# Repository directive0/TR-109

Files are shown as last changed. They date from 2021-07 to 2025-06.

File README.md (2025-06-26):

#
This repository hosts a set of design documents for the TR-109 Mark I Picorder. A Picorder is a Raspberry Pi based handheld device that records and displays sensor data for immediate analysis. The TR-109 is designed to use a Raspberry Pi Zero W, a set of custom designed PCBs, and a 3D printed enclosure to achieve this goal. This project, along with [PicorderOS](https://squaredwave.com/wiki/index.php?title=PicorderOS) attempts to be a single self contained solution for anyone wishing to produce their own Picorder.

## What is included:

- The enclosure_design folder contains the .blend file used to produce the STLs for the case, diffusers and spacers. It also contains the main STLs ready to be printed, and an svg file to produce your own stickers.

- The pcb_design folder contains KiCad 5.1.10 files of both the main board, sensor board and indicator board pcbs. These files can be used to produce and test PCBs. There is some PCBWay files that may be useful with their Assembly service, but this is not finalized and may not work properly.

## What is not yet included:

- There are no assembly instructions. I hope to produce some in the future.

While it is not required, if you make a picorder using this repository I would appreciate you sharing photos or videos your build with me at chris@squaredwave.com.

For a more regularly updated description of this project please visit the [wiki](https://squaredwave.com/wiki/index.php?title=Picorder_2)

Originally designed by Chris Barrett in 2021. I consider this project to be "Open Hardware", and as such is free to use, modify distribute or sell. It comes with no promise of support or warranty.

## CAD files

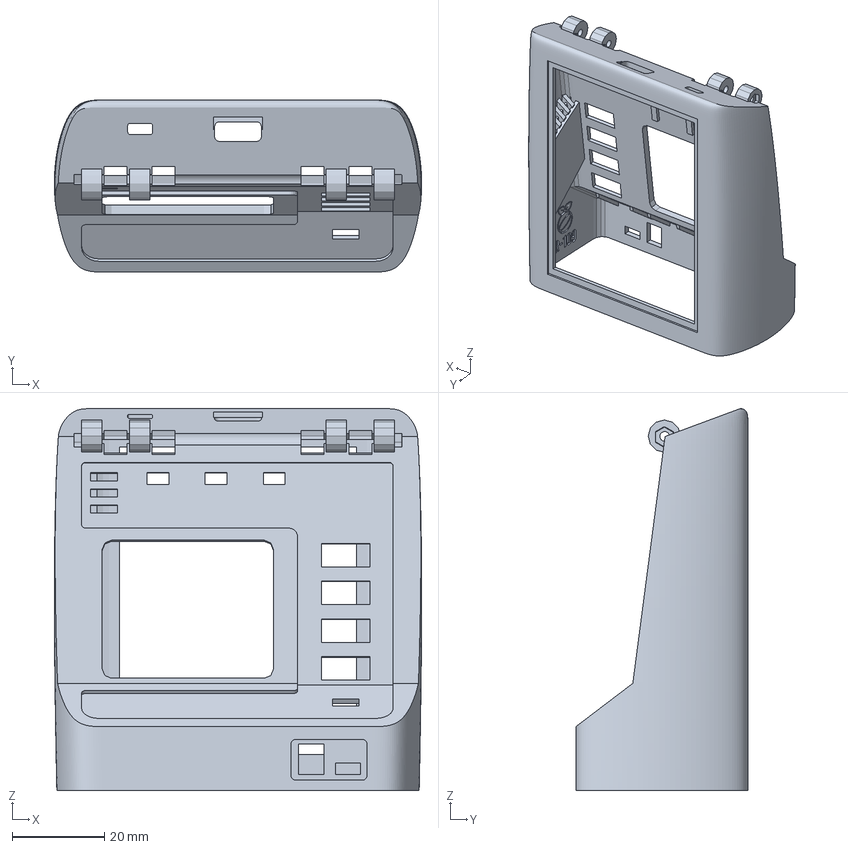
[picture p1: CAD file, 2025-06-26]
enclosure_design/Slicer Setup/TR109 - Main Body.3mf
79.5 x 37.3 x 82.7 mm

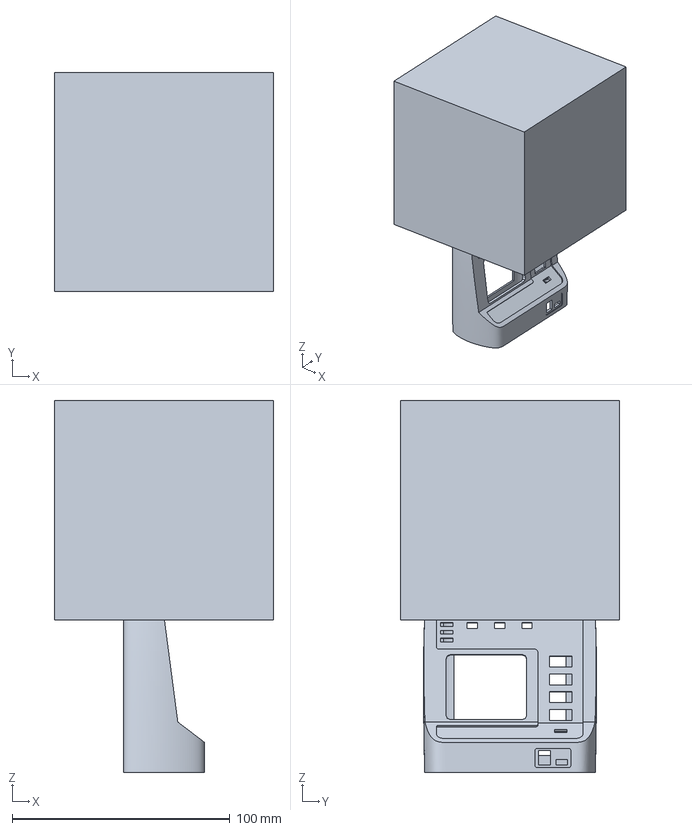
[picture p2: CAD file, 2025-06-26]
enclosure_design/Cura/TR109 - Main Body.3mf
100.8 x 100.8 x 170.9 mm

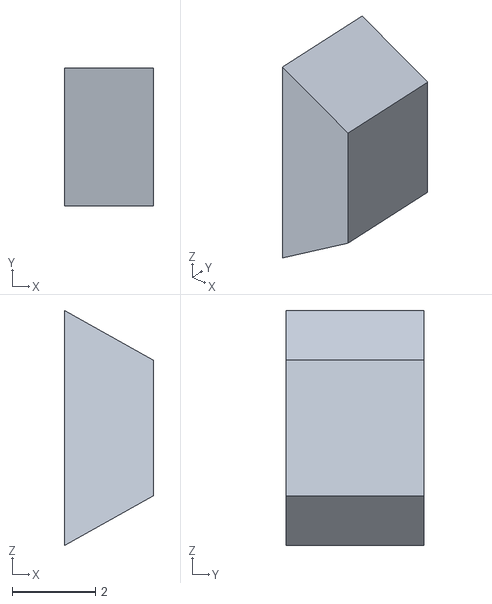
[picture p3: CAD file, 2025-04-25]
enclosure_design/STLs/Main Shell Tab.stl
2.14 x 3.33 x 5.66

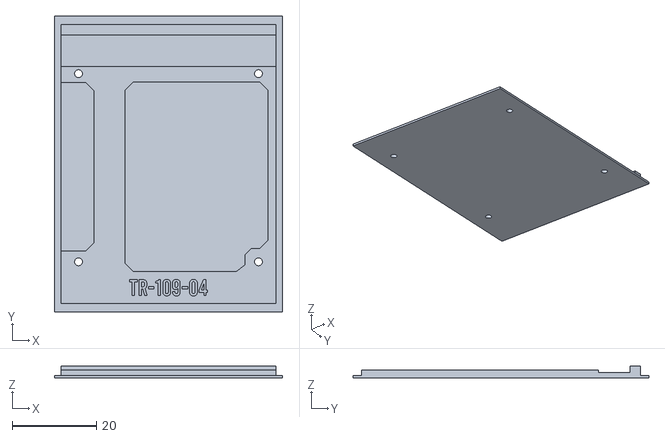
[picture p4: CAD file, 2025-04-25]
enclosure_design/STLs/TR109 - Main Shell Access Panel.stl
54.1 x 70.1 x 2.86

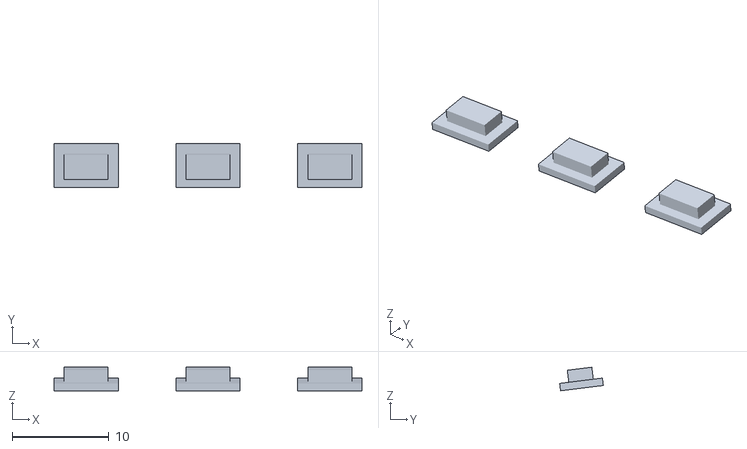
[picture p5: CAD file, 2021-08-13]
enclosure_design/STLs/Clear Diffuser Parts/TR109 - Diffuser - Main Body - Bio Met Geo.stl
31.8 x 4.52 x 2.44

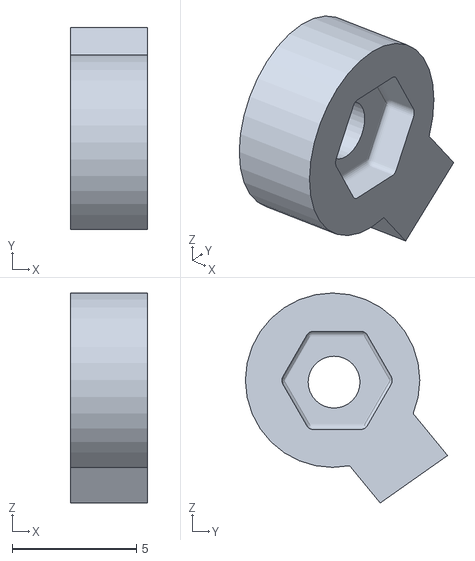
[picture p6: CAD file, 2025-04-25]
enclosure_design/STLs/TR109 - Main Body - Hinge Right.stl
3.10 x 8.14 x 8.46

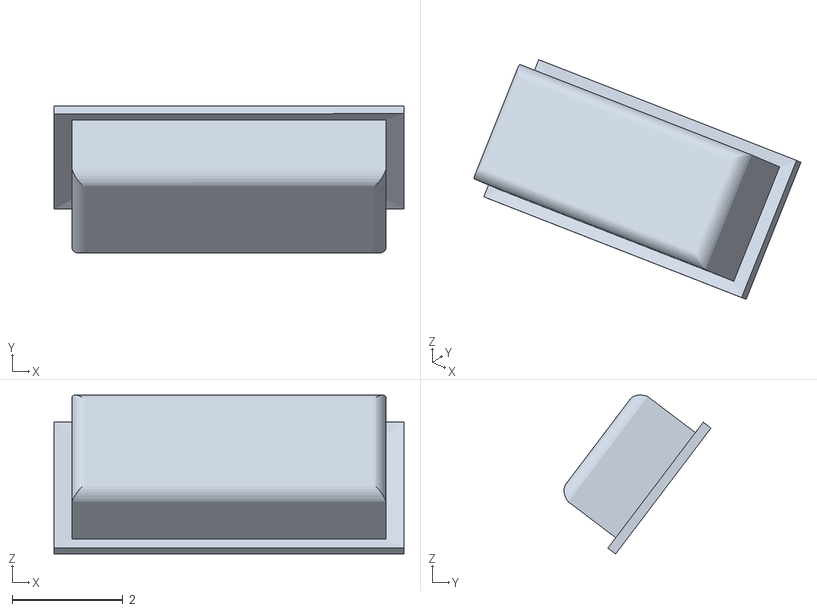
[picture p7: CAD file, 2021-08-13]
enclosure_design/STLs/Clear Diffuser Parts/TR109 - Diffuser - Main Body - PWR DIffuser.stl
6.32 x 2.66 x 2.87

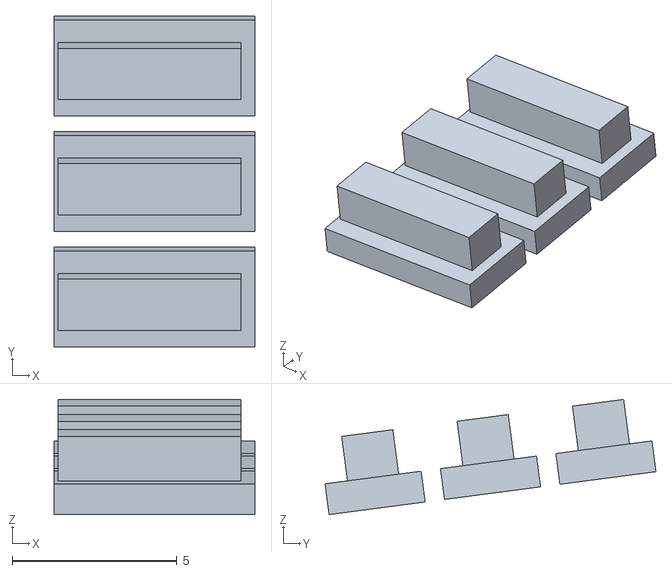
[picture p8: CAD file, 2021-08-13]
enclosure_design/STLs/Clear Diffuser Parts/TR109 - Diffuser - Main Body - Lower Right.stl
6.09 x 10.0 x 3.49

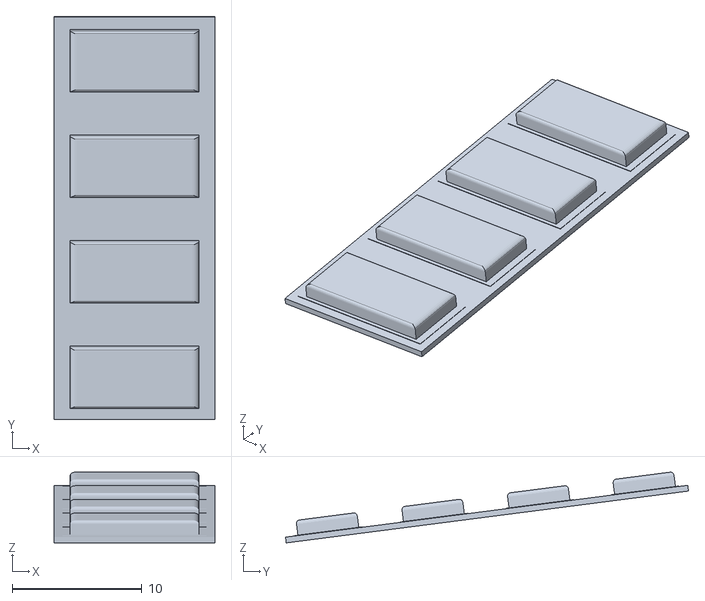
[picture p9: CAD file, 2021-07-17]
enclosure_design/STLs/Clear Diffuser Parts/TR109 - Diffuser - Main Body - ABGD.stl
12.4 x 31.0 x 5.45

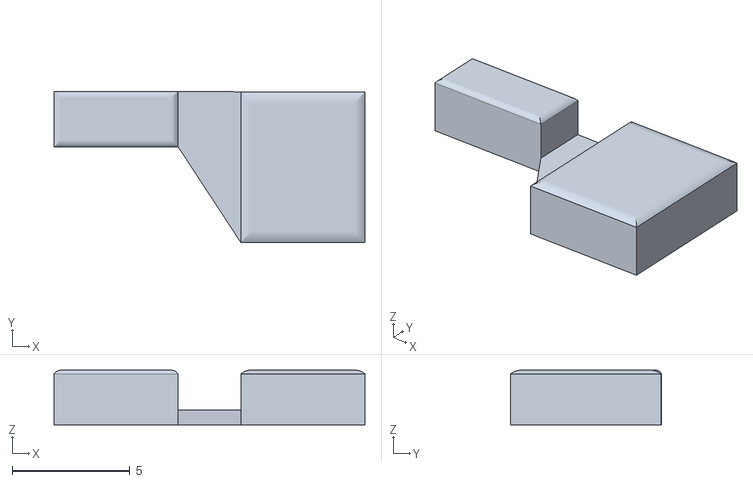
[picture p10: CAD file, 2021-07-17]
enclosure_design/STLs/Clear Diffuser Parts/TR109 - Diffuser - Main Body - ACT Diffuser.stl
13.2 x 6.42 x 2.33

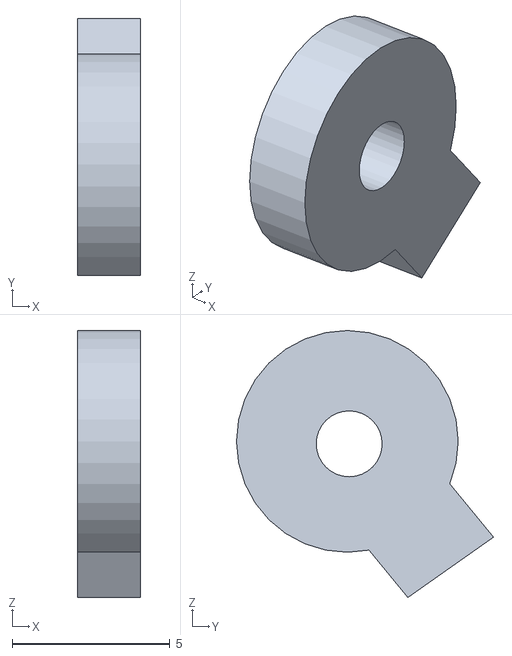
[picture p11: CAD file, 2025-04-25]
enclosure_design/STLs/TR109 - Main Body - Hinge Interior.stl
2.00 x 8.14 x 8.46

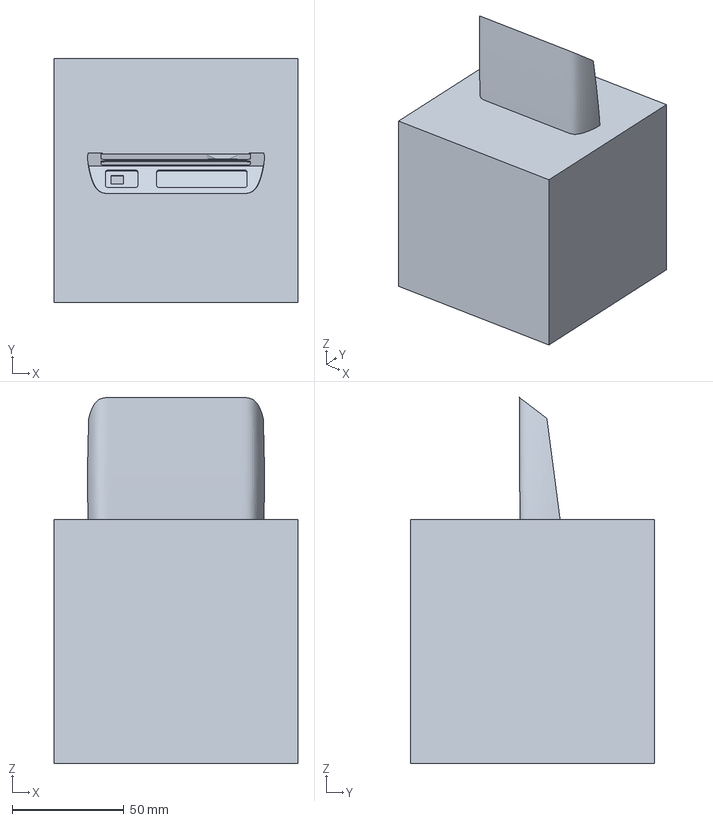
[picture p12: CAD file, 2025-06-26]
enclosure_design/Cura/Door.3mf
109.1 x 109.1 x 163.8 mm

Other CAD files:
enclosure_design/STLs/TR109 - Main Body Mk3.stl
enclosure_design/STLs/TR109 - Main Body.stl
enclosure_design/STLs/TR109 - Main Body - tr-109-04.stl
enclosure_design/STLs/TR109 - Main Body - Hinge Left.stl
enclosure_design/STLs/TR109 - Main Body - tr-109-03.stl
enclosure_design/STLs/TR109 - Main Body - Hingeless.stl
enclosure_design/STLs/Clear Diffuser Parts/TR109 - Diffuser - Door - EMRG.stl
enclosure_design/STLs/Clear Diffuser Parts/TR109 - Diffuser - Door - ID.stl
enclosure_design/STLs/Clear Diffuser Parts/TR109 - Diffuser - Ripple.stl
enclosure_design/STLs/Clear Diffuser Parts/TR109 - Diffuser - Sensor - 3mm LED Dummy.stl
enclosure_design/STLs/Clear Diffuser Parts/TR109 - Diffuser - Sensor - Lower Left Strip.stl
enclosure_design/STLs/Clear Diffuser Parts/TR109 - Diffuser - Sensor - Lower Right Strip.stl
enclosure_design/STLs/Clear Diffuser Parts/TR109 - Diffuser - Sensor - Ripple.stl
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

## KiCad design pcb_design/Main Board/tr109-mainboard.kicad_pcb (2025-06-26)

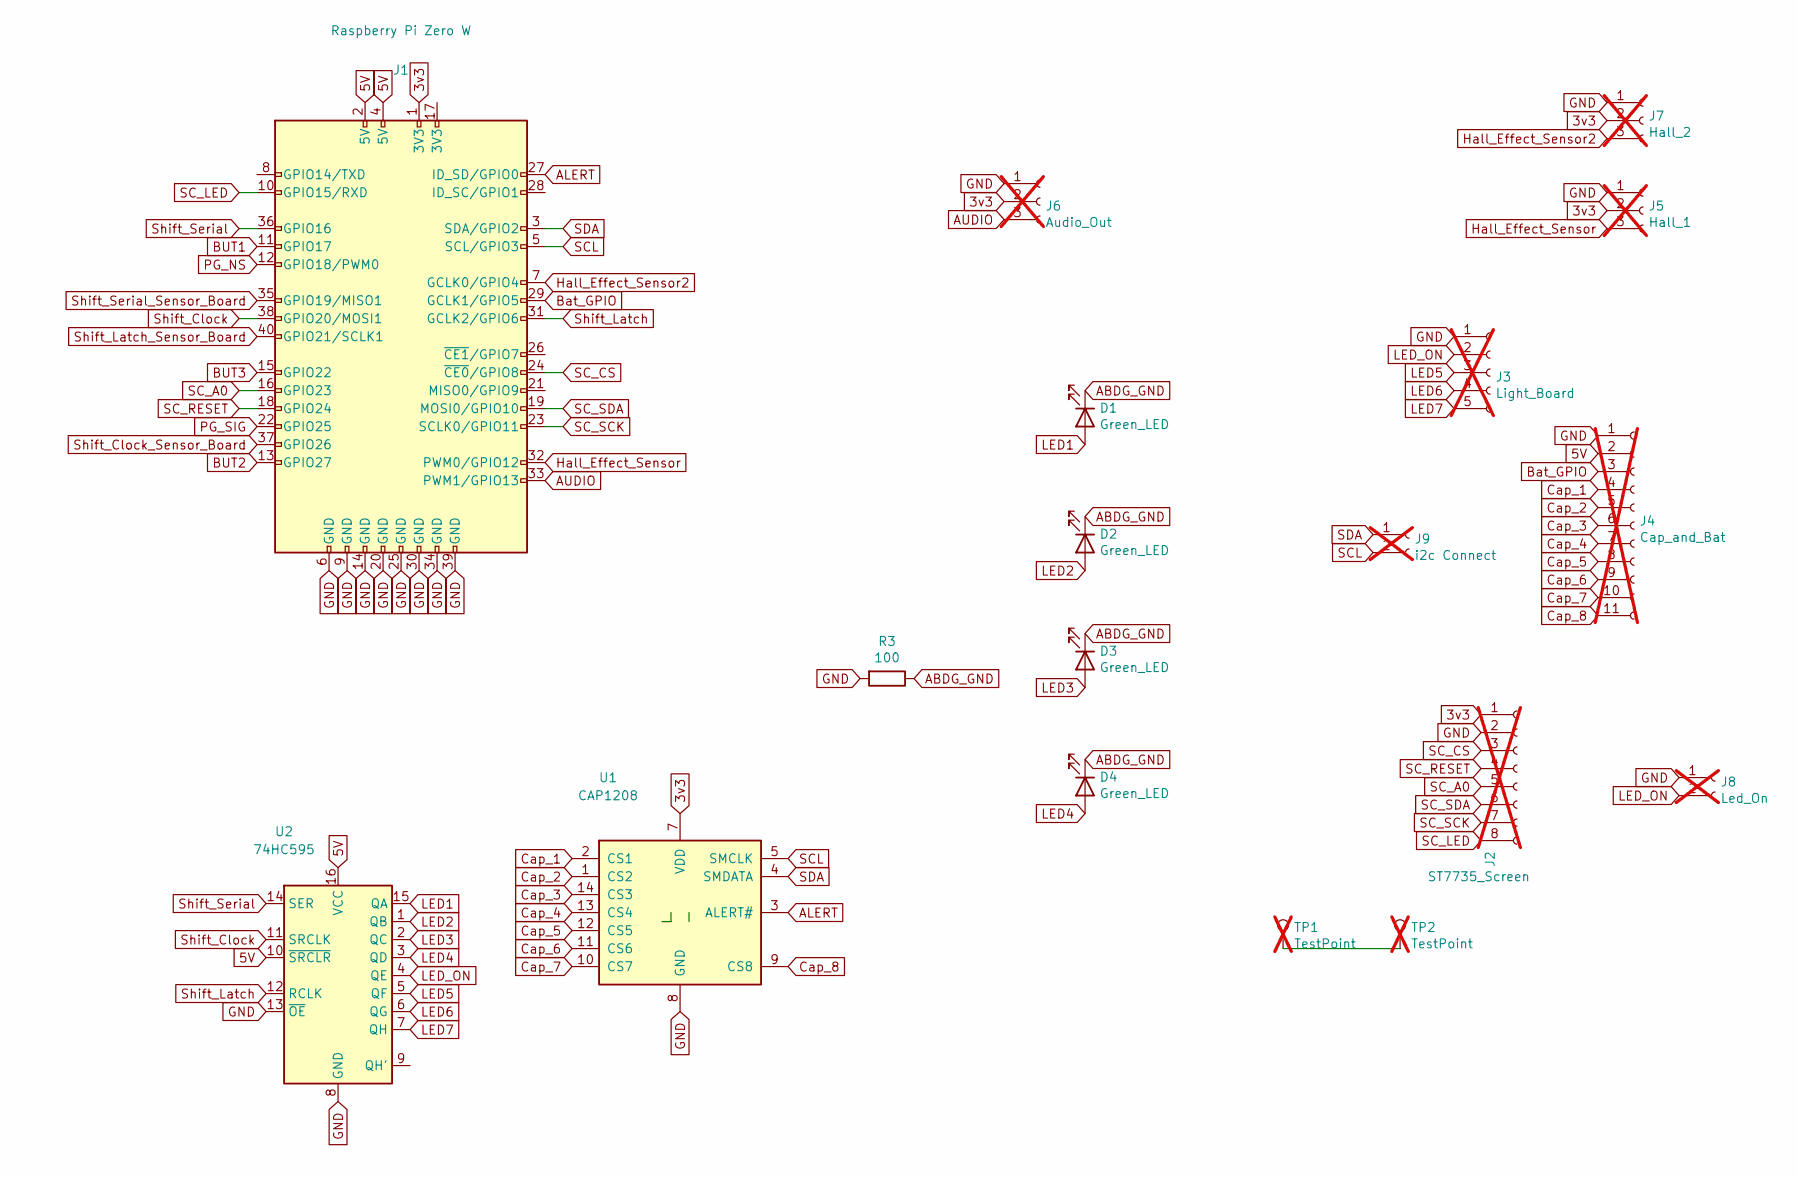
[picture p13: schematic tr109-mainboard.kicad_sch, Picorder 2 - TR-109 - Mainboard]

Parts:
D1, D2, D3, D4: Green_LED; LED_D3.0mm
J1: Raspberry Pi Zero W; PinHeader_2x20_P2.54mm_Horizontal
J2: ST7735_Screen; PinHeader_1x08_P2.54mm_Vertical; not fitted
J3: Light_Board; PinHeader_1x05_P2.54mm_Vertical; not fitted
J4: Cap_and_Bat; PinHeader_1x11_P2.54mm_Vertical; not fitted
J5: Hall_1; PinHeader_1x03_P2.54mm_Vertical; not fitted
J6: Audio_Out; PinHeader_1x03_P2.54mm_Vertical; not fitted
J7: Hall_2; PinHeader_1x03_P2.54mm_Vertical; not fitted
J8: Led_On; PinHeader_1x02_P2.54mm_Vertical; not fitted
J9: i2c Connect; PinHeader_1x02_P2.54mm_Vertical; not fitted
R3: 100; R_0805_2012Metric_Pad1.20x1.40mm_HandSolder
TP1, TP2: TestPoint; TestPoint_Pad_1.0x1.0mm; not fitted
U1: CAP1208; SOIC-14_3.9x8.7mm_P1.27mm
U2: 74HC595; SOIC-16_3.9x9.9mm_P1.27mm

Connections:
3v3: J1.1 (3V3), J2.1, J5.2, J6.2, J7.2, U1.7 (VDD)
5V: J1.2 (5V), J1.4 (5V), J4.2, U2.10 (~SRCLR), U2.16 (VCC)
ABDG_GND: D1.1 (K), D2.1 (K), D3.1 (K), D4.1 (K), R3.1
ALERT: J1.27 (ID_SD/GPIO0), U1.3 (ALERT#)
AUDIO: J1.33 (PWM1/GPIO13), J6.3
BUT1: J1.11 (GPIO17)
BUT2: J1.13 (GPIO27)
BUT3: J1.15 (GPIO22)
Bat_GPIO: J1.29 (GCLK1/GPIO5), J4.3
Cap_1: J4.4, U1.2 (CS1)
Cap_2: J4.5, U1.1 (CS2)
Cap_3: J4.6, U1.14 (CS3)
Cap_4: J4.7, U1.13 (CS4)
Cap_5: J4.8, U1.12 (CS5)
Cap_6: J4.9, U1.11 (CS6)
Cap_7: J4.10, U1.10 (CS7)
Cap_8: J4.11, U1.9 (CS8)
GND: J1.6 (GND), J1.9 (GND), J1.14 (GND), J1.20 (GND), J1.25 (GND), J1.30 (GND), J1.34 (GND), J1.39 (GND), J2.2, J3.1, J4.1, J5.1, J6.1, J7.1, J8.1, R3.2, U1.8 (GND), U2.8 (GND), U2.13 (~OE)
Hall_Effect_Sensor: J1.32 (PWM0/GPIO12), J5.3
Hall_Effect_Sensor2: J1.7 (GCLK0/GPIO4), J7.3
LED1: D1.2 (A), U2.15 (QA)
LED2: D2.2 (A), U2.1 (QB)
LED3: D3.2 (A), U2.2 (QC)
LED4: D4.2 (A), U2.3 (QD)
LED5: J3.3, U2.5 (QF)
LED6: J3.4, U2.6 (QG)
LED7: J3.5, U2.7 (QH)
LED_ON: J3.2, J8.2, U2.4 (QE)
unnamed: TP1.1, TP2.1
PG_NS: J1.12 (GPIO18/PWM0)
PG_SIG: J1.22 (GPIO25)
SCL: J1.5 (SCL/GPIO3), J9.2, U1.5 (SMCLK)
SC_A0: J1.16 (GPIO23), J2.5
SC_CS: J1.24 (~CE0/GPIO8), J2.3
SC_LED: J1.10 (GPIO15/RXD), J2.8
SC_RESET: J1.18 (GPIO24), J2.4
SC_SCK: J1.23 (SCLK0/GPIO11), J2.7
SC_SDA: J1.19 (MOSI0/GPIO10), J2.6
SDA: J1.3 (SDA/GPIO2), J9.1, U1.4 (SMDATA)
Shift_Clock: J1.38 (GPIO20/MOSI1), U2.11 (SRCLK)
Shift_Clock_Sensor_Board: J1.37 (GPIO26)
Shift_Latch: J1.31 (GCLK2/GPIO6), U2.12 (RCLK)
Shift_Latch_Sensor_Board: J1.40 (GPIO21/SCLK1)
Shift_Serial: J1.36 (GPIO16), U2.14 (SER)
Shift_Serial_Sensor_Board: J1.35 (GPIO19/MISO1)

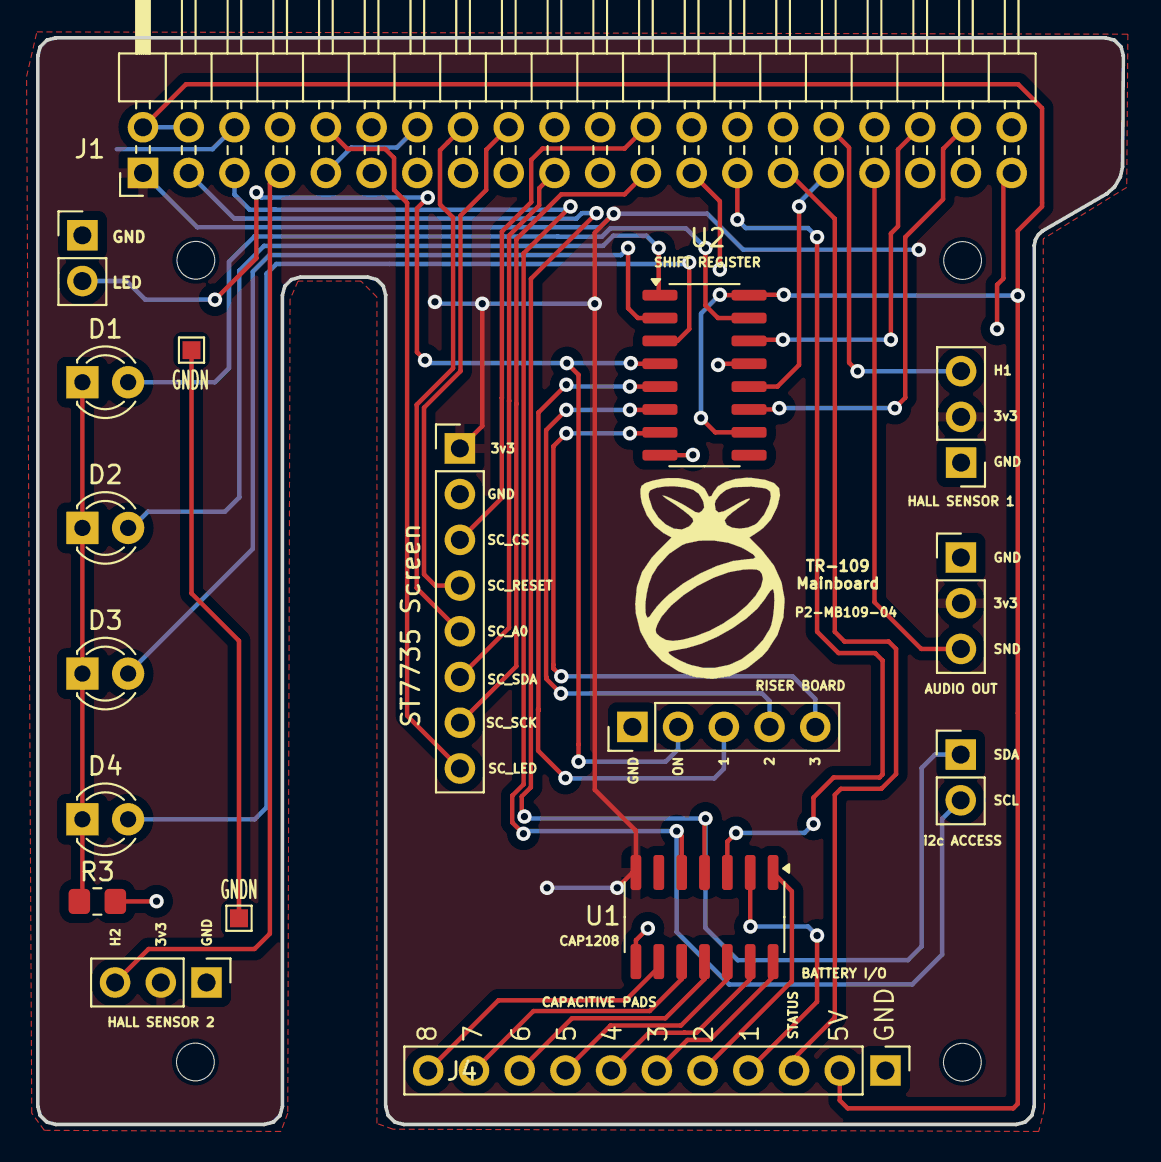
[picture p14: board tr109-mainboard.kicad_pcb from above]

Board: 2 copper layers, 60.3 x 60.4 mm, 18 parts (0 on the bottom side), 37 nets.

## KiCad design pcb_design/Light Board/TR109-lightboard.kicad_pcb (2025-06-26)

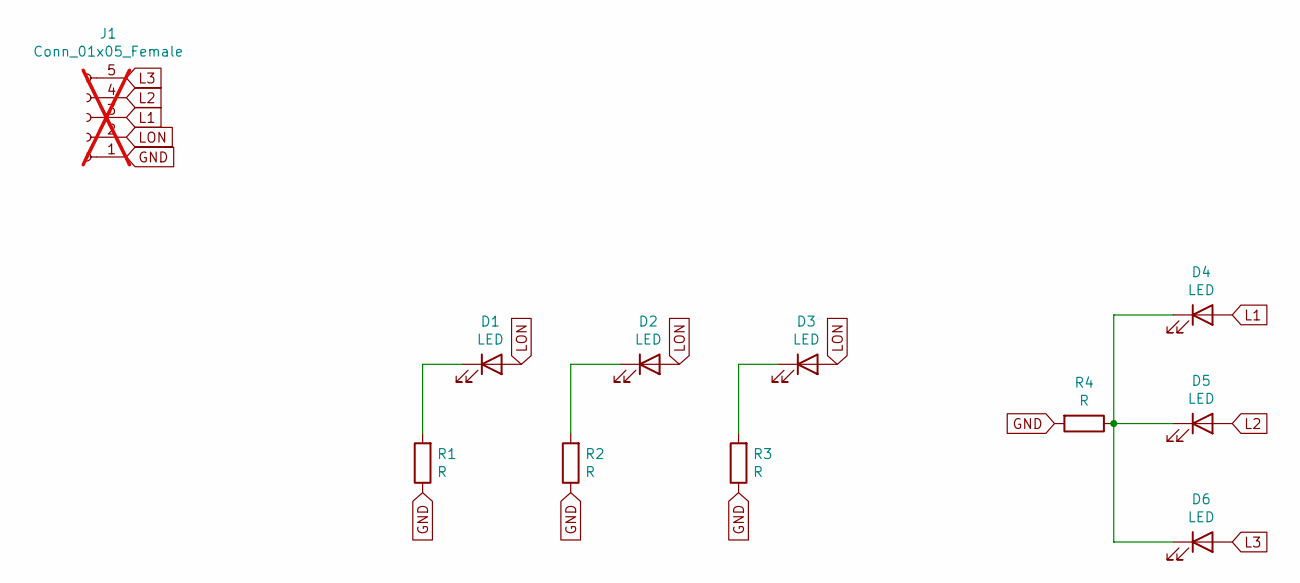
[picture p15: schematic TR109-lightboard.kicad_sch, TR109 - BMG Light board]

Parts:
D1, D2, D3, D4, D5, D6: LED; LED_1206_3216Metric_Pad1.42x1.75mm_HandSolder
J1: Conn_01x05_Female; PinHeader_1x05_P2.00mm_Vertical; not fitted
R1, R2, R3, R4: R; R_0805_2012Metric_Pad1.20x1.40mm_HandSolder

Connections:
GND: J1.1, R1.1, R2.1, R3.1, R4.2
L1: D4.2 (A), J1.3
L2: D5.2 (A), J1.4
L3: D6.2 (A), J1.5
LON: D1.2 (A), D2.2 (A), D3.2 (A), J1.2
unnamed: D1.1 (K), R1.2
unnamed: D2.1 (K), R2.2
unnamed: D3.1 (K), R3.2
unnamed: D4.1 (K), D5.1 (K), D6.1 (K), R4.1

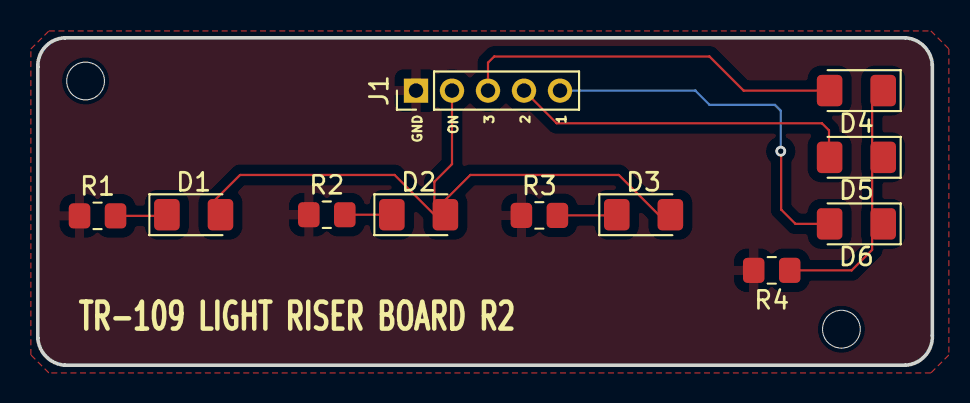
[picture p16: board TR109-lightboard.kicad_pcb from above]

Board: 2 copper layers, 49.7 x 18.2 mm, 11 parts (0 on the bottom side), 9 nets.

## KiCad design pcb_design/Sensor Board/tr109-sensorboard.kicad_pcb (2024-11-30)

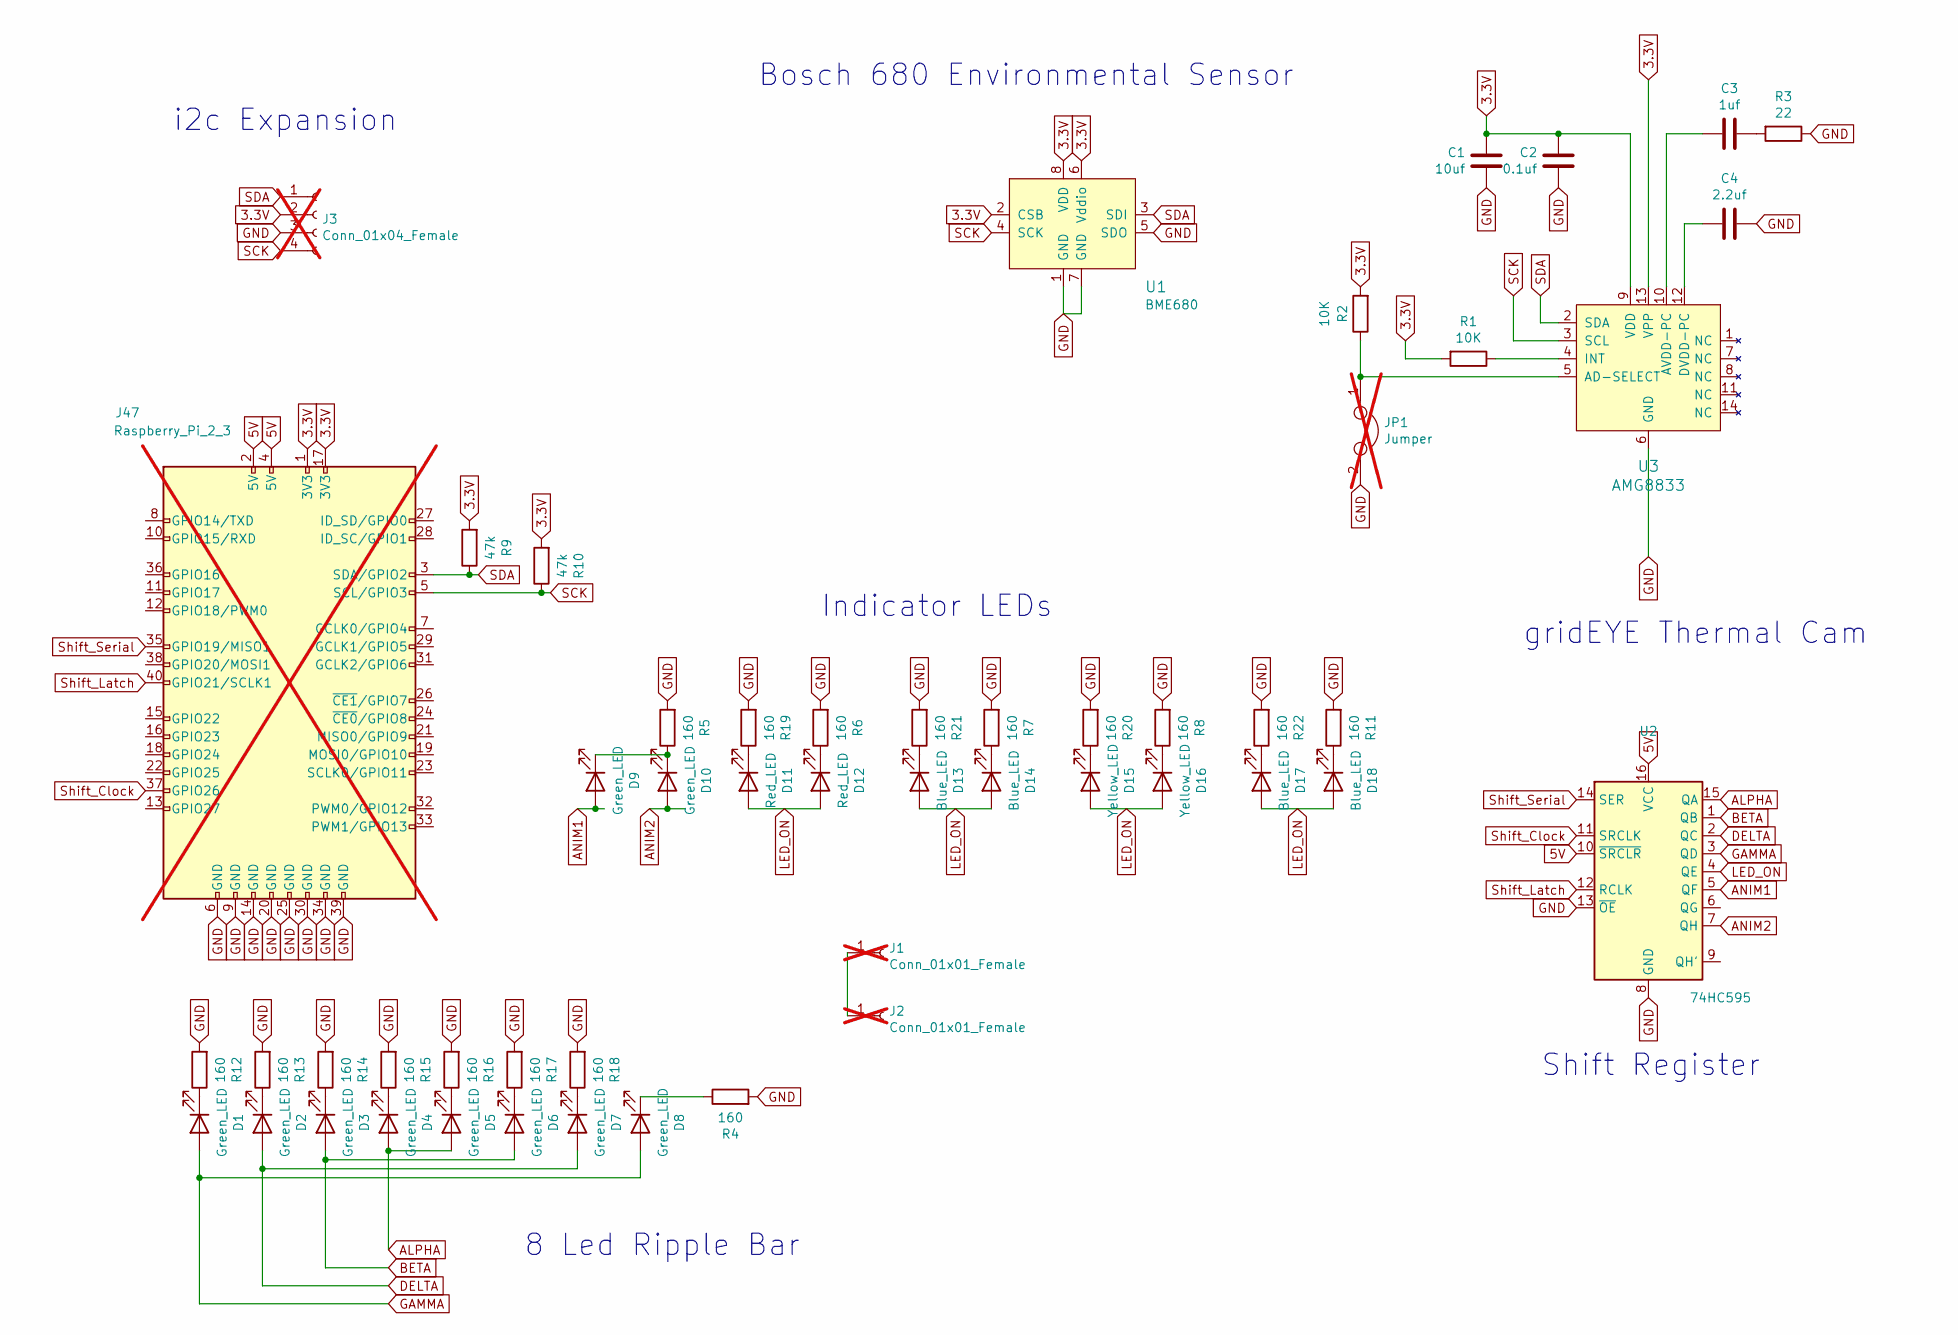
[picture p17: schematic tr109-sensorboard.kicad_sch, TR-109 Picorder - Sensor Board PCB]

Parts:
C1: 10uf; C_0805_2012Metric
C2: 0.1uf; C_0805_2012Metric
C3: 1uf; C_0805_2012Metric
C4: 2.2uf; C_0805_2012Metric
D1, D2, D3, D4, D5, D6, D7, D8, D9, D10: Green_LED; LED_1206_3216Metric_Pad1.42x1.75mm_HandSolder
D11, D12: Red_LED; LED_1206_3216Metric_Pad1.42x1.75mm_HandSolder
D13, D14, D17, D18: Blue_LED; LED_1206_3216Metric_Pad1.42x1.75mm_HandSolder
D15, D16: Yellow_LED; LED_1206_3216Metric_Pad1.42x1.75mm_HandSolder
J1, J2: Conn_01x01_Female; TestPoint_Pad_1.0x1.0mm; not fitted
J3: Conn_01x04_Female; PinHeader_1x04_P2.54mm_Vertical; not fitted
J47: Raspberry_Pi_2_3; PinHeader_2x20_P2.54mm_Vertical; not fitted
JP1: Jumper; SolderJumper-2_P1.3mm_Open_Pad1.0x1.5mm; not fitted
R1, R2: 10K; R_0805_2012Metric_Pad1.15x1.40mm_HandSolder
R3: 22; R_0805_2012Metric_Pad1.15x1.40mm_HandSolder
R4, R5, R6, R7, R8, R11, R12, R13, R14, R15, R16, R17, R18, R19, R20, R21, R22: 160; R_0805_2012Metric_Pad1.15x1.40mm_HandSolder
R9, R10: 47k; R_0805_2012Metric_Pad1.15x1.40mm_HandSolder
U1: BME680; MPN BME680; Digi-Key_PN 828-1077-1-ND
U2: 74HC595; SOIC-16_3.9x9.9mm_P1.27mm
U3: AMG8833; SMD-14_Grideye; MPN AMG8833; Digi-Key_PN P19002CT-ND

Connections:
3.3V: C1.2, C2.2, J3.2, J47.1 (3V3), J47.17 (3V3), R1.2, R2.2, R9.2, R10.2, U1.2 (CSB), U1.6 (Vddio), U1.8 (VDD), U3.9 (VDD), U3.13 (VPP)
5V: J47.2 (5V), J47.4 (5V), U2.10 (~SRCLR), U2.16 (VCC)
ALPHA: D4.2 (A), D5.2 (A), U2.15 (QA)
ANIM1: D9.2 (A), U2.5 (QF)
ANIM2: D10.2 (A), U2.7 (QH)
BETA: D3.2 (A), D6.2 (A), U2.1 (QB)
DELTA: D2.2 (A), D7.2 (A), U2.2 (QC)
GAMMA: D1.2 (A), D8.2 (A), U2.3 (QD)
GND: C1.1, C2.1, C4.2, J3.3, J47.6 (GND), J47.9 (GND), J47.14 (GND), J47.20 (GND), J47.25 (GND), J47.30 (GND), J47.34 (GND), J47.39 (GND), JP1.2, R3.1, R4.2, R5.2, R6.2, R7.2, R8.2, R11.2, R12.2, R13.2, R14.2, R15.2, R16.2, R17.2, R18.2, R19.2, R20.2, R21.2, R22.2, U1.1 (GND), U1.5 (SDO), U1.7 (GND), U2.8 (GND), U2.13 (~OE), U3.6 (GND)
LED_ON: D11.2 (A), D12.2 (A), D13.2 (A), D14.2 (A), D15.2 (A), D16.2 (A), D17.2 (A), D18.2 (A), U2.4 (QE)
unnamed: C3.2, R3.2
unnamed: D1.1 (K), R12.1
unnamed: D2.1 (K), R13.1
unnamed: D3.1 (K), R14.1
unnamed: D4.1 (K), R15.1
unnamed: D5.1 (K), R16.1
unnamed: D6.1 (K), R17.1
unnamed: D7.1 (K), R18.1
unnamed: D8.1 (K), R4.1
unnamed: D9.1 (K), D10.1 (K), R5.1
unnamed: D11.1 (K), R19.1
unnamed: D12.1 (K), R6.1
unnamed: D13.1 (K), R21.1
unnamed: D14.1 (K), R7.1
unnamed: D15.1 (K), R20.1
unnamed: D16.1 (K), R8.1
unnamed: D17.1 (K), R22.1
unnamed: D18.1 (K), R11.1
unnamed: J1.1, J2.1
unnamed: JP1.1, R2.1, U3.5 (AD-SELECT)
unnamed: C3.1, U3.10 (AVDD-PC)
unnamed: C4.1, U3.12 (DVDD-PC)
unnamed: R1.1, U3.4 (INT)
SCK: J3.4, J47.5 (SCL/GPIO3), R10.1, U1.4 (SCK), U3.3 (SCL)
SDA: J3.1, J47.3 (SDA/GPIO2), R9.1, U1.3 (SDI), U3.2 (SDA)
Shift_Clock: J47.37 (GPIO26), U2.11 (SRCLK)
Shift_Latch: J47.40 (GPIO21/SCLK1), U2.12 (RCLK)
Shift_Serial: J47.35 (GPIO19/MISO1), U2.14 (SER)

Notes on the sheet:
Indicator LEDs
i2c Expansion
gridEYE Thermal Cam
Shift Register
8 Led Ripple Bar
Bosch 680 Environmental Sensor

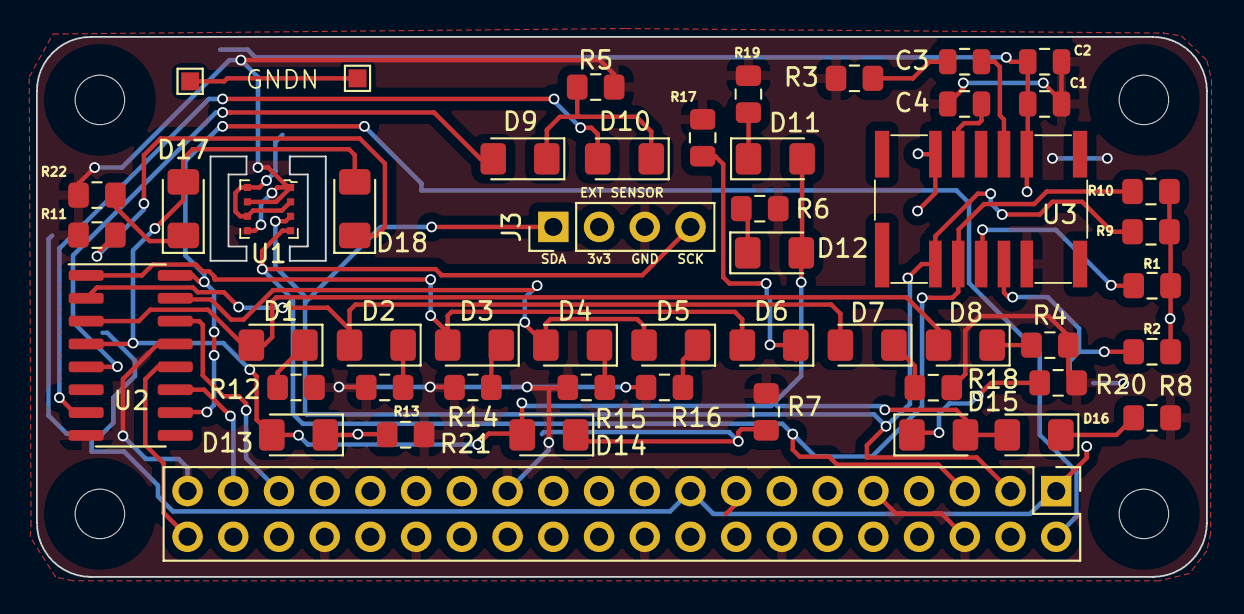
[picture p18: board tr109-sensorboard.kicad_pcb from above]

Board: 2 copper layers, 65.0 x 30.0 mm, 52 parts (1 on the bottom side), 38 nets.

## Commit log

2021-05-02 Initial File Upload
    [tr-109 picorder shell-Chassis_v5.stl, tr-109 picorder shell-Mark_2_Door.stl, tr-109 picorder shell-Mark_2_End_Cap.stl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]
2021-05-25 cleanup and revisions
    changes to the sensor and main boards
    clean up of the blender file to remove some deprecated meshes
    [tr109-mainboard.kicad_pcb, tr109-mainboard.sch, tr109-sensorboard.kicad_pcb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]
2021-05-28 more case changes
2021-05-28 STL and Blend Changes
    Clean up to Blend file, re-export of STLs for scaling issues
    [TR109 - Chassis.stl, TR109 - Diffuser - Door - EMRG.stl, TR109 - Diffuser - Door - ID.stl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]
2021-05-29 bmg pcb
2021-05-29 refinements to bmg pcb
2021-05-29 sensor board revisions
    [tr109-sensorboard.kicad_pcb, tr109-sensorboard.sch]
2021-05-29 sensor board schematic
    [tr109-sensorboard.sch]
2021-06-05 pcb and shell changes
    [TR109 - Diffuser - Door - ID.stl, TR109-lightboard.kicad_pcb, TR109-lightboard.sch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]
2021-06-08 Pcb and shell design work
    [TR109-lightboard.kicad_pcb, tr109-mainboard.kicad_pcb, tr109-mainboard.sch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]
2021-06-25 Rev 3 board changes, blender file changes
    [TR109-lightboard-B_Adhes.gbr, TR109-lightboard-B_CrtYd.gbr, TR109-lightboard-B_Cu.gbr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]
2021-06-25 Kicad Sheet Title Corrections
    [TR109-lightboard.sch, tr109-mainboard.sch, tr109-sensorboard.sch]
2021-06-29 more blend changes
    [tr-109 picorder shell-Mark_2_Door.stl]
2021-07-02 Blender updates.
    [tr109-sensorboard.kicad_pcb]
2021-07-17 Pcb and enclosure changes for proto 01
    [TR109 - Chassis.stl, TR109 - Diffuser - Main Body - ACT Diffuser.stl, TR109 - Diffuser - Ripple.stl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]
2021-08-13 changes to shell and pcb
    [TR109 - Diffuser - Main Body - ABGD.stl, TR109 - Diffuser - Main Body - Bio Met Geo.stl, TR109 - Diffuser - Main Body - Lower Right.stl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]
2021-08-23 Unit 01
    [TR109 - Access Panel.stl, TR109 - Diffuser - Door - EMRG.stl, TR109 - Diffuser - Door - ID.stl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]
2021-08-27 parts changes
    [TR109-lightboard.kicad_pcb, TR109-lightboard.sch]
2024-11-30 Kicad V8 updates
    Changes to board and improvements. Needs Kicad V8 now.
    [tr109-mainboard.csv, tr109-mainboard.kicad_pcb, tr109-mainboard.kicad_pcb_bom.csv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]
2024-11-30 kicad v8
    [tr109-sensorboard-B_Cu.gbr, tr109-sensorboard-B_Mask.gbr, tr109-sensorboard-B_Paste.gbr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]
2025-04-25 Updated PCBs
    [Main Shell Tab.stl, TR109 - Access Panel.stl, TR109 - Capacitive Button Pads.stl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]
2025-06-26 Fixed some kicad PCB errors, updated Blender file
    [Door.3mf, TR-109 Sensor Board Shrouds.stl, TR109 - Door - EMRG Surround.stl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]
